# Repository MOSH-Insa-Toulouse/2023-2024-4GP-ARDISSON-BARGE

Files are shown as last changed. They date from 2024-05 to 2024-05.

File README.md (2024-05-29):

# 4GP 2023/2024 - Projet de capteur _low-tech_ en graphite - Par Cyril ARDISSON et Kévin BARGE <br>

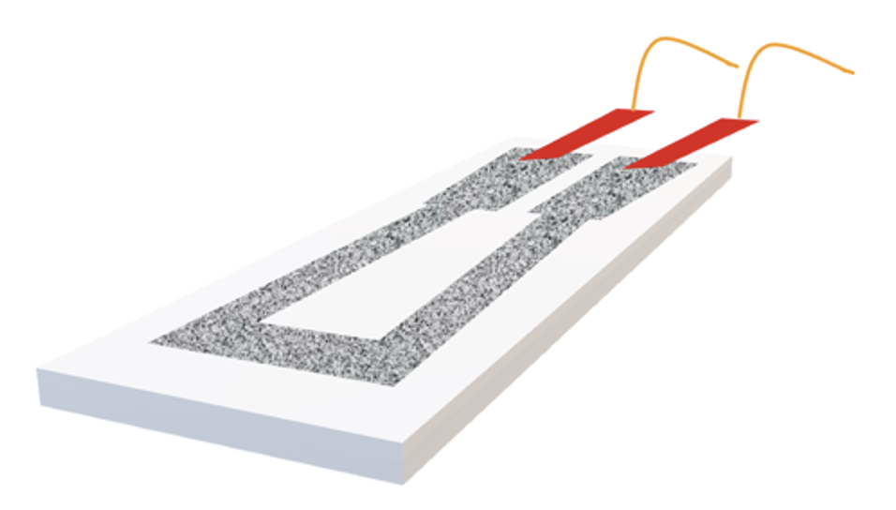
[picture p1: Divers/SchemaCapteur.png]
Visuel capteur


## Table des matières
✓ [Contacts](#contacts) <br>
✓ [Contexte](#contexte) <br>
✓ [Livrables](#livrables) <br>
✓ [Matériel requis](#matériel-requis) <br>
[1- Simulation sous LTSpice](#1--simulation-sous-ltspice) <br>
[2- Design du PCB sous KiCAD](#2--design-du-pcb-sous-kicad) <br>
[3- Code sous Arduino IDE](#3--code-sous-arduino-ide) <br>
[4- Application Android](#4--application-android) <br>
[5- Réalisation du shield](#5--réalisation-du-shield) <br>
[6- Banc de test et principaux résultats](#6--banc-de-test-et-principaux-résultats) <br>
[7- Datasheet du capteur](#7--datasheet-du-capteur) <br>
✓ [Conclusions et analyse critique du projet](#conclusions-et-analyse-critique-du-projet) <br>
___
## Contacts
Cyril ARDISSON : [ardisson@insa-toulouse.fr](mailto:ardisson@insa-toulouse.fr) <br>
Kévin BARGE : [barge@insa-toulouse.fr](mailto:barge@insa-toulouse.fr) <br>
___
## Contexte
Dans le cadre de l'UF de 4ème Année spécialité Génie Physique "Du capteur au banc de test" (I4GPMH21), nous avons réalisé l'évaluation d'une technologie low-tech : un capteur en graphite, composé de papier, recouvert d'une couche de graphite qu'on peut simplement trouver dans les crayons à papier ! En se déformant, le nombre de particules de graphite reliées varie, ce qui entraîne une modification de sa résistance. De cela, on peut donc induire la déformation. Sur le même principe qu'une jauge de contrainte (ici low-tech !). Ce travail se base sur les travaux de chercheurs de l'Université de Northwestern (Etats-Unis), publiés en 2014 dans l'article "_Pencil Drawn Strain Gauges and Chemiresistors on Paper_" (Cheng-Wei Lin, Zhibo Zhao, Jaemyung Kim & Jiaxing Huang). 

Afin de réaliser ce projet, plusieurs étapes ont été réalisées : simulation électronique, design de PCB et fabrication, programmation d'un Arduino Uno et d'une IHM, mise en place d'un banc de test et écriture d'une datasheet.

Ici, nous faisons le tour de tout ce qui a été fait dans le cadre de ce projet.

___
## Livrables
Plusieurs livrables sont attendus :

✓ **Le shield PCB connecté à une carte Arduino Uno**, composé : du capteur en graphite, d'un montage amplificateur transimpédance et d'un module Bluetooth. D'autres composants peuvent aussi être implémentés (*) : écran OLED, encodeur rotatoire, potentiomètre digital, flex sensor et connexions pour un servo-moteur ; <br>
✓ **Le code Arduino** permettant d'effectuer les mesures du capteur et de contrôler les composants implémentés ; <br>
✓ **L'APK Android** permettant d'interfacer le shield et le code Arduino correspondant : l'IHM en résumé ; <br>
✓ **Le / Les code(s) Arduino** permettant d'effectuer les tests du capteur ; <br>
✓ **La datasheet du capteur** reprenant toutes ses caractéristiques ainsi que ses tests. <br>

(*) Pour notre projet, nous avons décidés d'implémenter sur notre shield : l'écran OLED, l'encodeur rotatoire, le potentiomètre digital et le flex sensor. 
___
## Matériel requis
Afin de réaliser notre dispositif, nous avons eu besoin de :

Pour le montage amplificateur transimpédance : <br>
✓ Résistances : une de $1\ \text{k}\Omega$, une de $10\ \text{k}\Omega$ et deux de $100\ \text{k}\Omega$ - une troisième de $100\ \text{k}\Omega$ peut être prévue, mais peut aussi être substituée par une résistance variable (le potentiomètre digital), choix que l'on a fait ; <br>
✓ Un potentiomètre digital (si substitution d'une résistance de $100\ \text{k}\Omega$) : ici, choix du MCP41050 ; <br>
✓ Capacités : trois de $100\ \text{nF}$ et une de $1\ \mu\text{F}$ ; <br>
✓ Un amplificateur opérationnel : ici, choix du LTC1050 ; <br>

Pour le reste du dispositif : <br>
✓ Un module Bluetooth : ici, choix du HC05 ; <br>
✓ Un écran OLED de dimension 128*64 ; <br>
✓ Un encodeur rotatoire ; <br>
✓ Un flex sensor.
___
## 1- Simulation sous LTSpice
Notre capteur en graphite a une résistance de l'ordre du ${G}\Omega$, ce qui conduit, en appliquant une tension d'entrée de $5\ \text{V}$, à obtenir un courant de quelques ${nA}$. En conséquence, notre Arduino Uno ne pourra pas le lire. Il y a donc nécessité d'amplifier ce signal : c'est donc ce pourquoi nous mettons en place un **montage amplificateur transimpédance**. <br>

**_Description du montage amplificateur transimpédance_** <br>
Notre montage est composé de 4 zones importantes, une pour l'amplification et trois qui correspondent à des filtres : <br>
✓ Un premier filtre en entrée de l'amplificateur (${R1}$ et ${C1}$) : il correspond à un filtre passe-bas, qui permet de filtrer le bruit en courant sur le signal d'entrée ; <br>
✓ Un second filtre couplé à l'amplificateur (${R3}$ et ${C4}$) : il correspond aussi à un filtre passe-bas, qui permet de filtrer la composante 50 Hz du réseau électrique ; <br>
✓ et un troisième filtre en sorti de l'amplificateur (${R6}$ et ${C2}$) : pour filtrer le bruit lié au traitement opéré par l'amplificateur. <br>

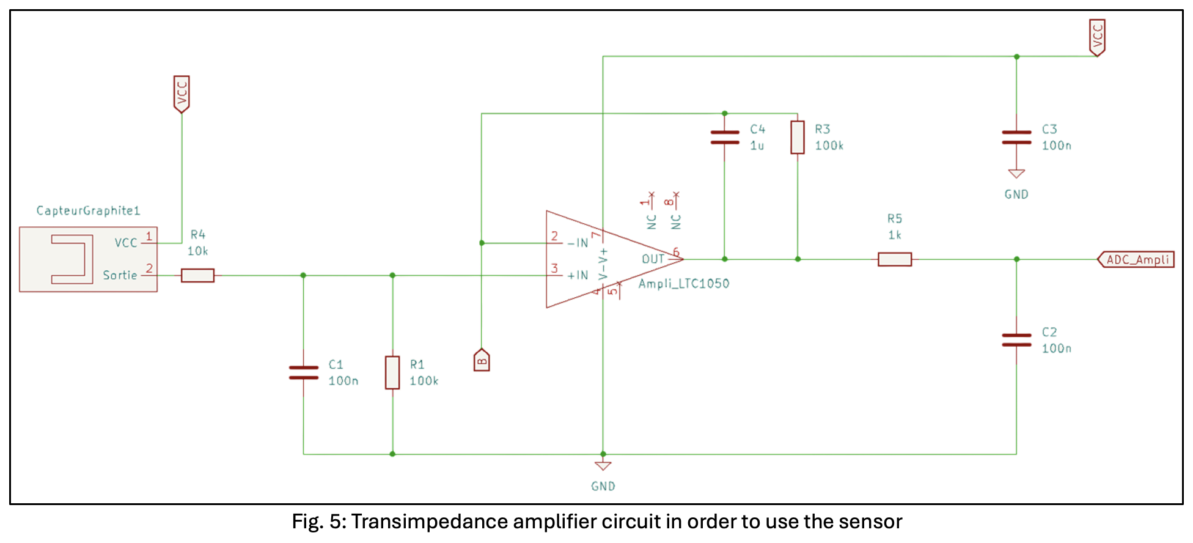
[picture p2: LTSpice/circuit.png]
Montage amplificateur transimpédance
<br>

Sur LTSpice, nous avons testé ce montage en deux temps. <br>

**_Simulations réalisées avec LTSpice_** <br>
Sur LTSpice, nous avons testé ce montage en deux temps. <br>

D'abord, nous avons effectué une première simulation pour vérifier si l'amplification était bien effective. Comme on peut le constater ci-dessous, le signal est bien amplifié à $1\ \text{V}$ : l'Arduino pourra donc l'interpréter. <br>

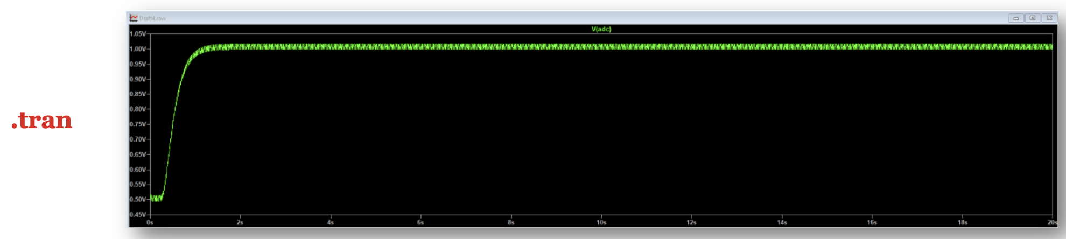
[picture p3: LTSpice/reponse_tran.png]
Réponse à .tran
<br>

Enfin, nous avons effectué une seconde simulation, afin d'observer la réponse à un courant alternatif et ainsi de vérifier que le signal est bien filtré. Comme on peut aussi le constater ci-dessous, le signal paraît filtré, successivement par les 3 filtres. <br>

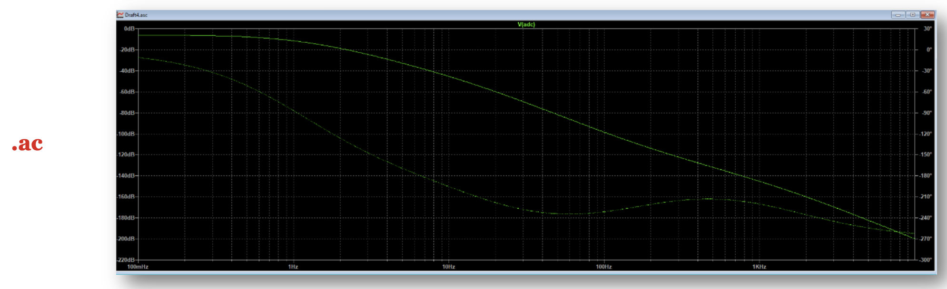
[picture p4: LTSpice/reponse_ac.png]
Réponse à .ac
<br><br>
___
## 2- Design du PCB sous KiCAD
Ici, nous sommes repartis du montage décrit ci-dessus, avec quelques modifications et ajouts de composants. Nous avons utilisé le logiciel KiCad 7.0 : <br>
✓ Comme mentionné auparavant, nous avons remplacé ${R2}$ par le potentiomètre digital ; <br>
✓ Ajout d'un module Bluetooth afin d'assurer la communication entre le PCB et l'APK Android ; <br>
✓ Ajout d'un écran OLED afin d'afficher 3 menus différents ; <br>
✓ Ajout d'un encodeur rotatoire afin de passer de menu en menu ; <br>
✓ Et enfin, ajout d'un flex sensor, en vu des tests finaux. <br>

Pour se faire, nous avons débuté par la création de notre propre bibliothèque de symboles correspondant à nos composants. Puis, nous avons procédé à la création de la schématique électrique de l'ensemble du montage. L'image ci-dessous correspond à cette schématique. <br>

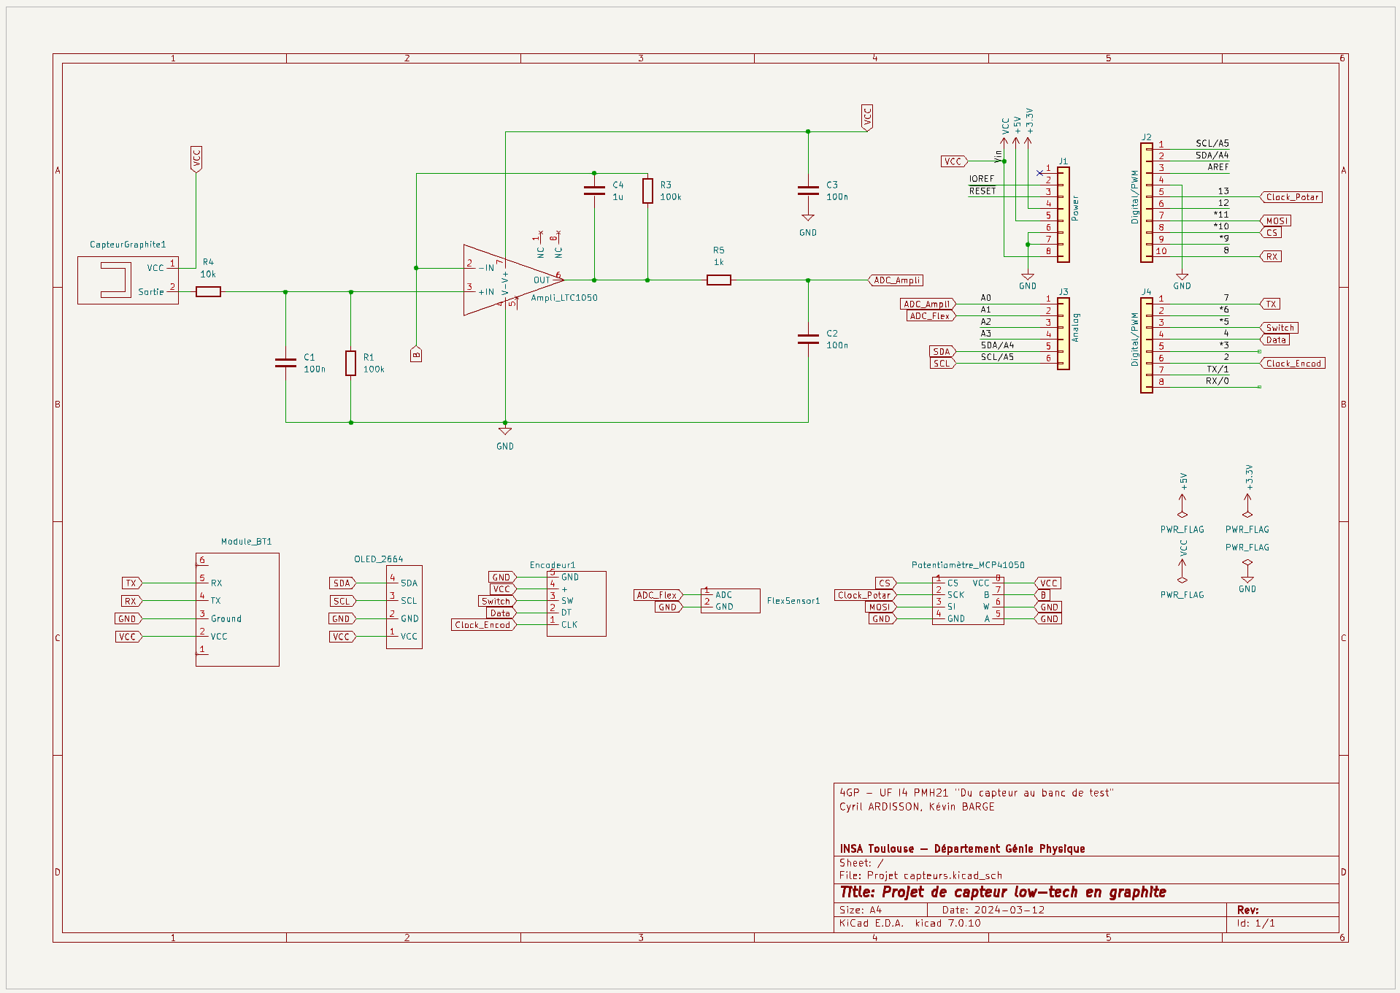
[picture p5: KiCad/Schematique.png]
Schématique KiCad
 <br>

Puis, nous avons créé les empreintes de nos composants, en respectant certaines dimensions, en vu de l'impression du PCB (diamètre des trous, forme des empreintes, etc.). Nous sommes ensuite passés à la disposition des composants sur le PCB : une étape fastidieuse avec des compromis afin d'obtenir le placement le plus efficace (en considérant les connexions entre composants, en évitant d'avoir recours aux vias, etc.)... L'image ci-dessous correspond au résultat final de notre PCB, et sa vue en 3D correspondante :

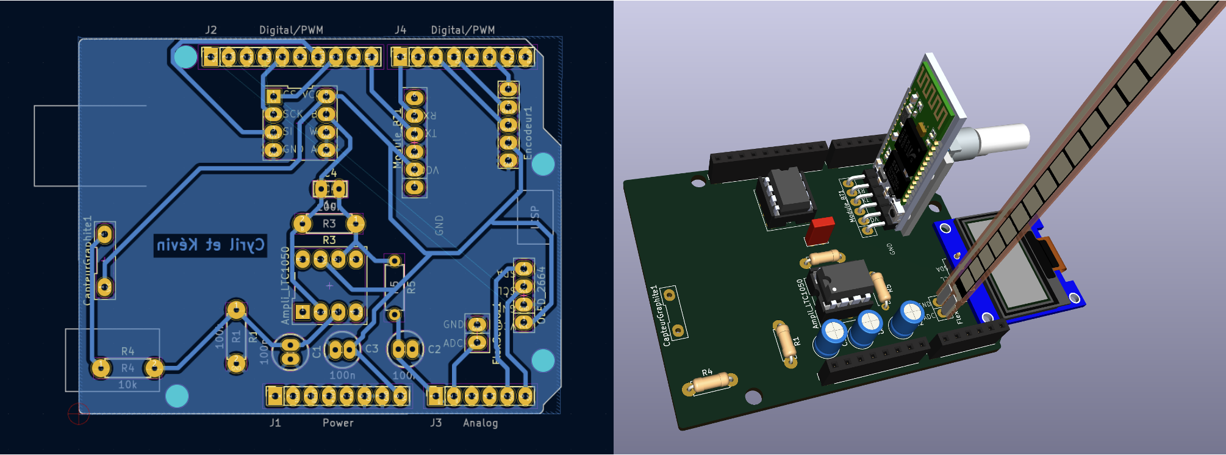
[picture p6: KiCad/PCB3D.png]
PCB et vue 3B
 <br>

Les fichiers KiCad sont disponibles dans le dossier [KiCad](https://github.com/MOSH-Insa-Toulouse/2023-2024-4GP-ARDISSON-BARGE/tree/main/KiCad). 
___
## 3- Code sous Arduino IDE
Le code de contrôle, qui permet d'effectuer les mesures du capteur et de contrôler les composants implémentés, a été développé sous Arduino IDE 2.3.2. <br>

Pour communiquer en Bluetooth, nous avons utilisé la bibliothèque _SoftwareSerial.h_ et pour contrôler l'écran OLED, la bibliothèque _Adafruit_SSD1306.h_. <br>

Notamment, en plus de la communication Bluetooth entre notre PCB et l'application Bluetooth, notre code permet de contrôler deux menus à afficher sur l'écran OLED : <br>
✓ Un menu pour afficher la résistance du capteur _en direct_ ; <br>
✓ Et un menu pour afficher la résistance du flex sensor _en direct_. <br>

Les mesures se font toutes les 100 ms. <br>

Le code complet est disponible [ici](https://github.com/MOSH-Insa-Toulouse/2023-2024-4GP-ARDISSON-BARGE/blob/main/ArduinoIDE/ARDISSON-BARGE_CodeFinal.ino). <br>
___
## 4- Application Android
Nous avons créé une application en guise d'interface, avec MIT App Inventor. <br>

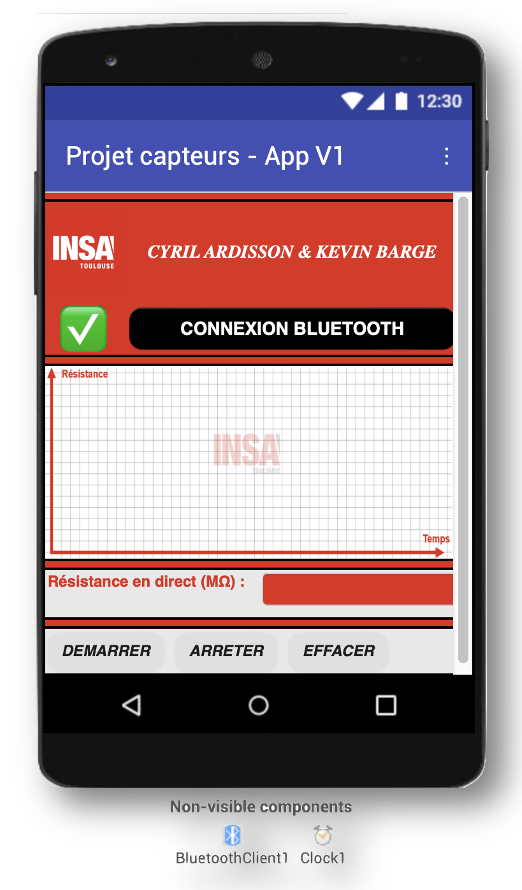
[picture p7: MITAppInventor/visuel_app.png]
Visuel de l'application
 <br>

Cette application se veut simple et permet : <br>
✓ De se connecter au module Bluetooth du PCB afin de communiquer avec ce dernier ; <br>
✓ D'afficher sur un graphe la résistance du capteur en fonction du temps (où on peut démarrer / arrêter l'acquisition + effacer le graphe) ; <br>
✓ Et d'afficher la résistance "en direct". <br>

_Néanmoins, on rencontre tout de même quelques problèmes de connexion entre l'app qu'on installe sur un smartphone Android et le module Bluetooth. Bien souvent, aucune donnée n'est récupérée._ <br>

L'application est disponible [ici](https://github.com/MOSH-Insa-Toulouse/2023-2024-4GP-ARDISSON-BARGE/blob/main/MITAppInventor). <br>
___
## 5- Réalisation du shield
Fin mars, nous avons pu passer à la réalisation _physique_ de notre PCB. Voici les étapes de fabrication réalisées, avec l'aide de Cathy Crouzet (_merci !_) : <br>

Étape 0 (_importante !_) : vérification du PCB sous KiCad, notamment test DRC <br>
Étape 1 : édition du masque de gravure sous KiCad <br>
Étape 2 : insolation UV d'une plaquette d'époxy (recouverte d'une couche de cuivre et de résine photosensible) <br>
Étape 3 : immersion de la plaquette dans un révélateur afin d'éliminer la résine non-insolée <br>
Étape 4 : immersion de la plaquette dans du perchlorure de fer pour graver les pistes <br>
Étape 5 : nettoyage de la plaquette avec de l'acétone pour retirer la résine restante <br>
Étape 6 : perçage des trous et placement des composants sur le PCB <br>

L'image ci-dessous illustre le rendu final de notre PCB : <br>

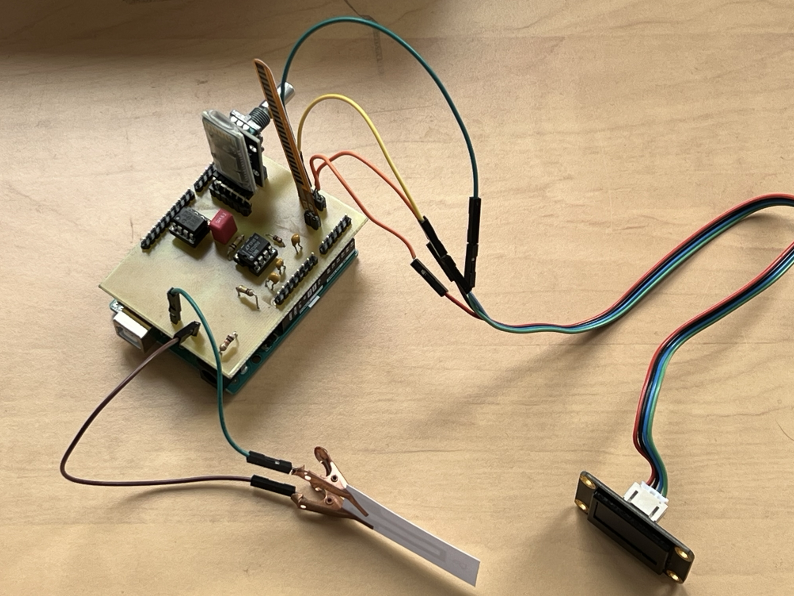
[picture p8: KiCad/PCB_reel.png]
PCB en vrai
 <br>
___
## 6- Banc de test et principaux résultats
Afin de tester nos capteurs, nous avons utilisés le banc de test suivant, composé de 7 demi-cercles, avec des diamètres de 2 à 5 cm (0,5 cm d'écart entre chaque). <br>

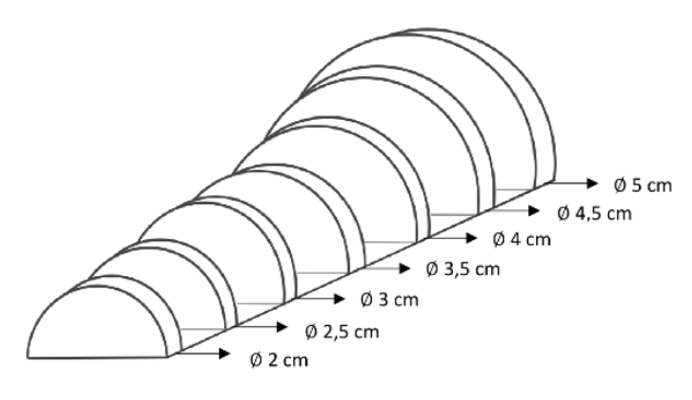
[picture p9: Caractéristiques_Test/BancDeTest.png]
Visuel banc de test
 <br>

Ce banc de test nous permet d'obtenir la variation de résistance $\frac{\Delta R}{R_0}$ en fonction de la déformation $\epsilon = \frac{e}{D}$ avec $e$ l'épaisseur du capteur (ici 0,2 mm) et $D$ le diamètre du cercle considéré. <br>

Nous avons réalisé les tests en *compression* et en *tension*. <br>

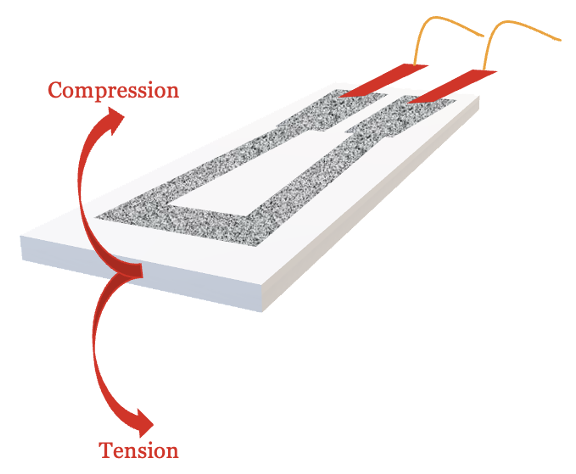
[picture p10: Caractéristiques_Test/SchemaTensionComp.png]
Visuel capteur en compression et tension
 <br>

Nous avons effectués les tests avec des capteurs recouverts de deux types de graphite différents : d'un crayon HB et d'un crayon 2B. (*) <br>

Voici les caractéristiques en compression : <br>
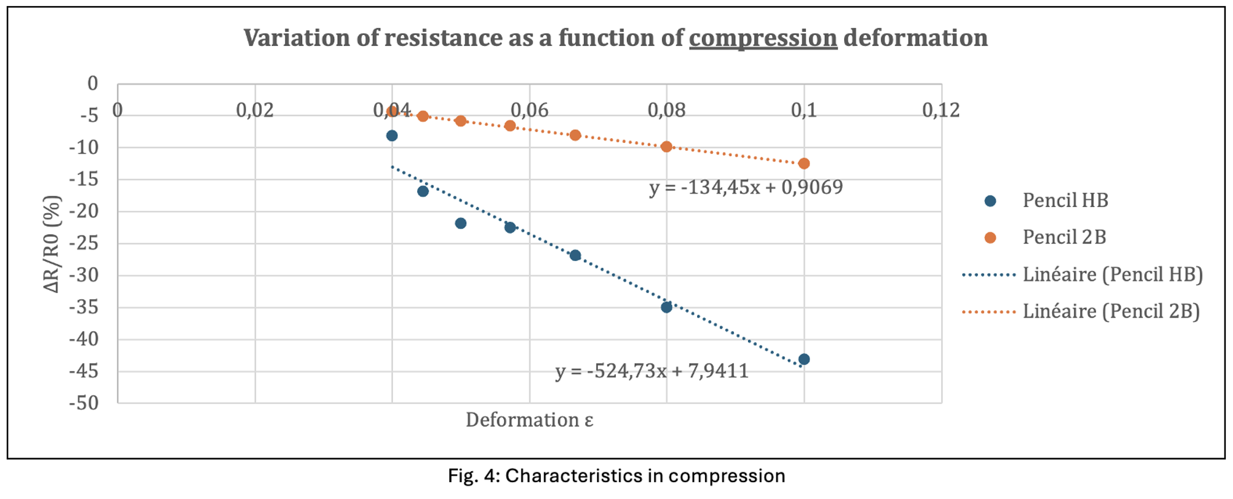
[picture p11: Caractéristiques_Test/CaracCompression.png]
Caractéristique en compression
 <br>

Et les caractéristiques en tension : <br>
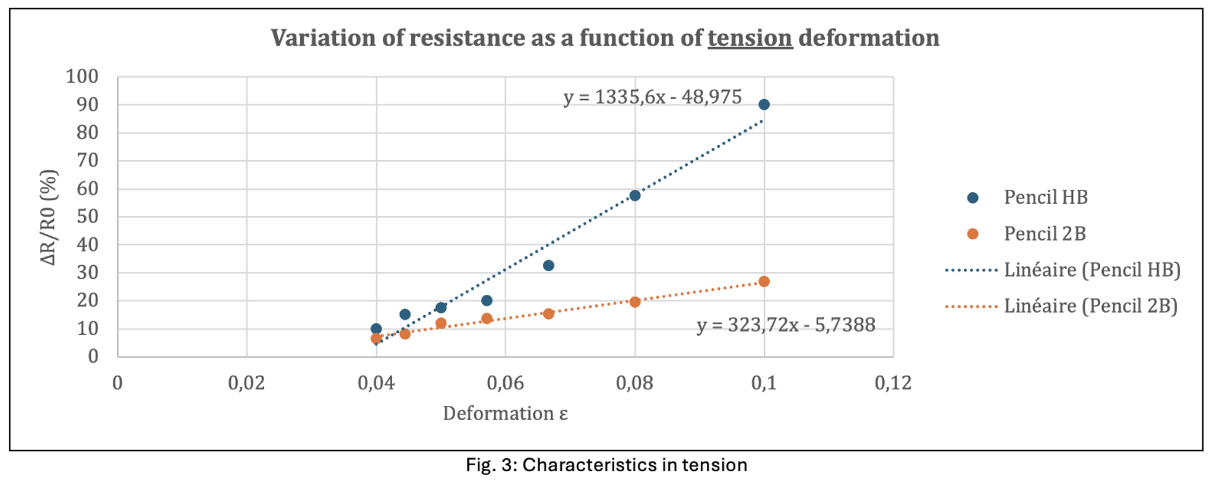
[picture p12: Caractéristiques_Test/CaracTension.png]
Caractéristique en tension
 <br>

On peut donc remarquer que la résistance diminue lorsqu'on augmente la compression, alors que la résistance augmente lorsqu'on augmente la tension. Ceci semble cohérent : en compression, la distance entre les atomes diminue et donc la résistance dimunue en conséquence. L'inverse est vrai en tension. <br>

De plus, on voit qu'avec un crayon plus gras (2B étant plus gras que HB - plus de carbone !), la variation relative de résistance est moins importante. 

Enfin, pour comparer, nous avons aussi réalisé le test en tension (car cela ne fonctionne pas en compression !) avec le flex sensor : <br>
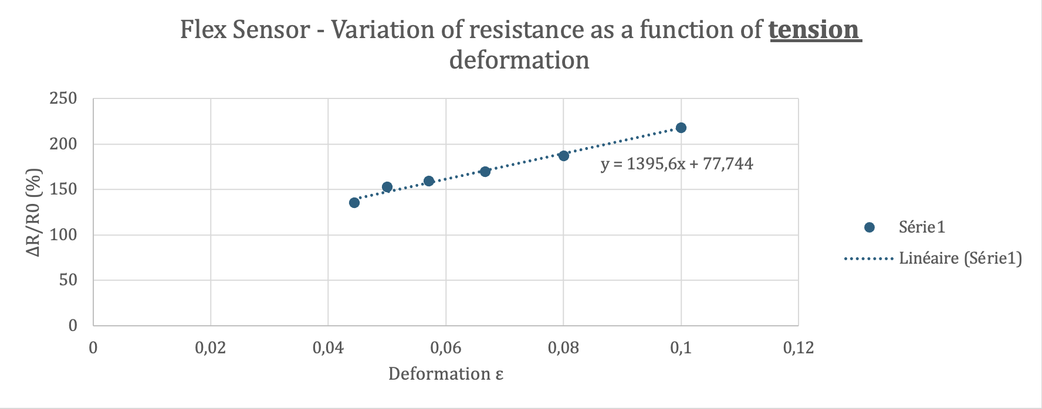
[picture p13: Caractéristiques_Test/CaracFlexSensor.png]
Caractéristique flex sensor
 <br>

On remarque donc que, en comparaison de nos capteurs, le flex sensor semble plus sensible, ce qui semble faire sens. Pour des déformations importantes, il semble aussi être plus apte à les tolérer, "plus solide". <br>

(*) _Nous voulions aussi tester notre capteur en graphite issu d'un crayon B, mais les tests n'étaient pas concluants. En effet, cette méthode de test donne des résultats assez aléatoirement. L'usage d'un servomoteur avec une inclinaison pas à pas sur les demi-cercles pourrait peut-être donner des résultats plus stables. Dans la même optique, une méthode de contrôle de la quantité de graphique déposée sur les capteurs serait la bienvenue, étant assez aléatoire. Tout cela conduit donc à avoir, en l'état, des conditions de test assez peu reconductibles._ <br>
___
## 7- Datasheet du capteur
La datasheet de notre capteur est disponible [ici](https://github.com/MOSH-Insa-Toulouse/2023-2024-4GP-ARDISSON-BARGE/blob/main/Datasheet/ARDISSON-BARGE_Datasheet.pdf).  <br>
___
## Conclusions et analyse critique du projet
Ce projet a été très enrichissant, nous donnant une réelle perspective du travail de l'ingénieur, en le conduisant de bout en bout, des simulations à la datasheet. On a pu avoir avoir une bonne perspective d'une variété de compétences (simulation électronique, développement informatique, design d'un montage électronique, fabrication _physique_ de ce dernier, etc.). En ce sens, c'est donc assez professionnalisant, et gratifiant d'avoir un produit final. <br>

En ce qui concerne le capteur produit, il est fonctionnel et les tests nous permettent de dégager des tendances cohérentes avec la physique. Néanmoins, comme souligné plus haut, les conditions de tests sont rudimentaires et peu reproductibles, ce qui conduit à tout de même obtenir des résultats assez aléatoires. Il faut donc prendre du recul. <br>

Maintenant, il est clair que dans un objectif pédagogique, ce projet est idéal ! <br>

_En espérant que notre société GazouTech va prospérer grâce à ce dernier !_ <br>

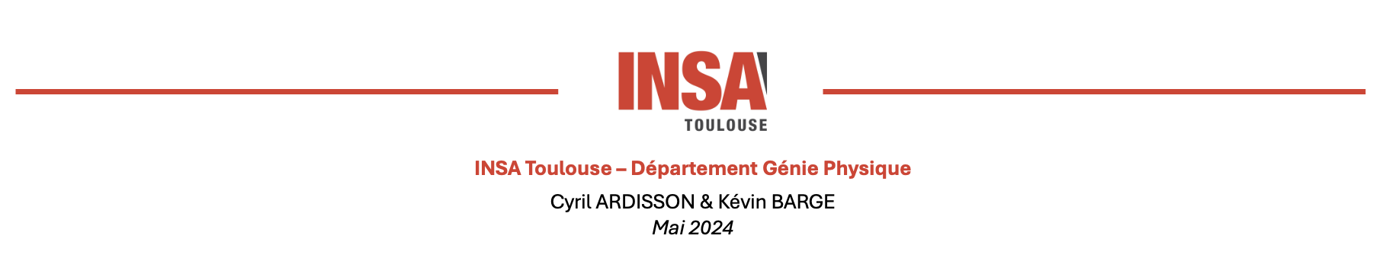
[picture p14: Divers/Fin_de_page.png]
Fin de page
<br>

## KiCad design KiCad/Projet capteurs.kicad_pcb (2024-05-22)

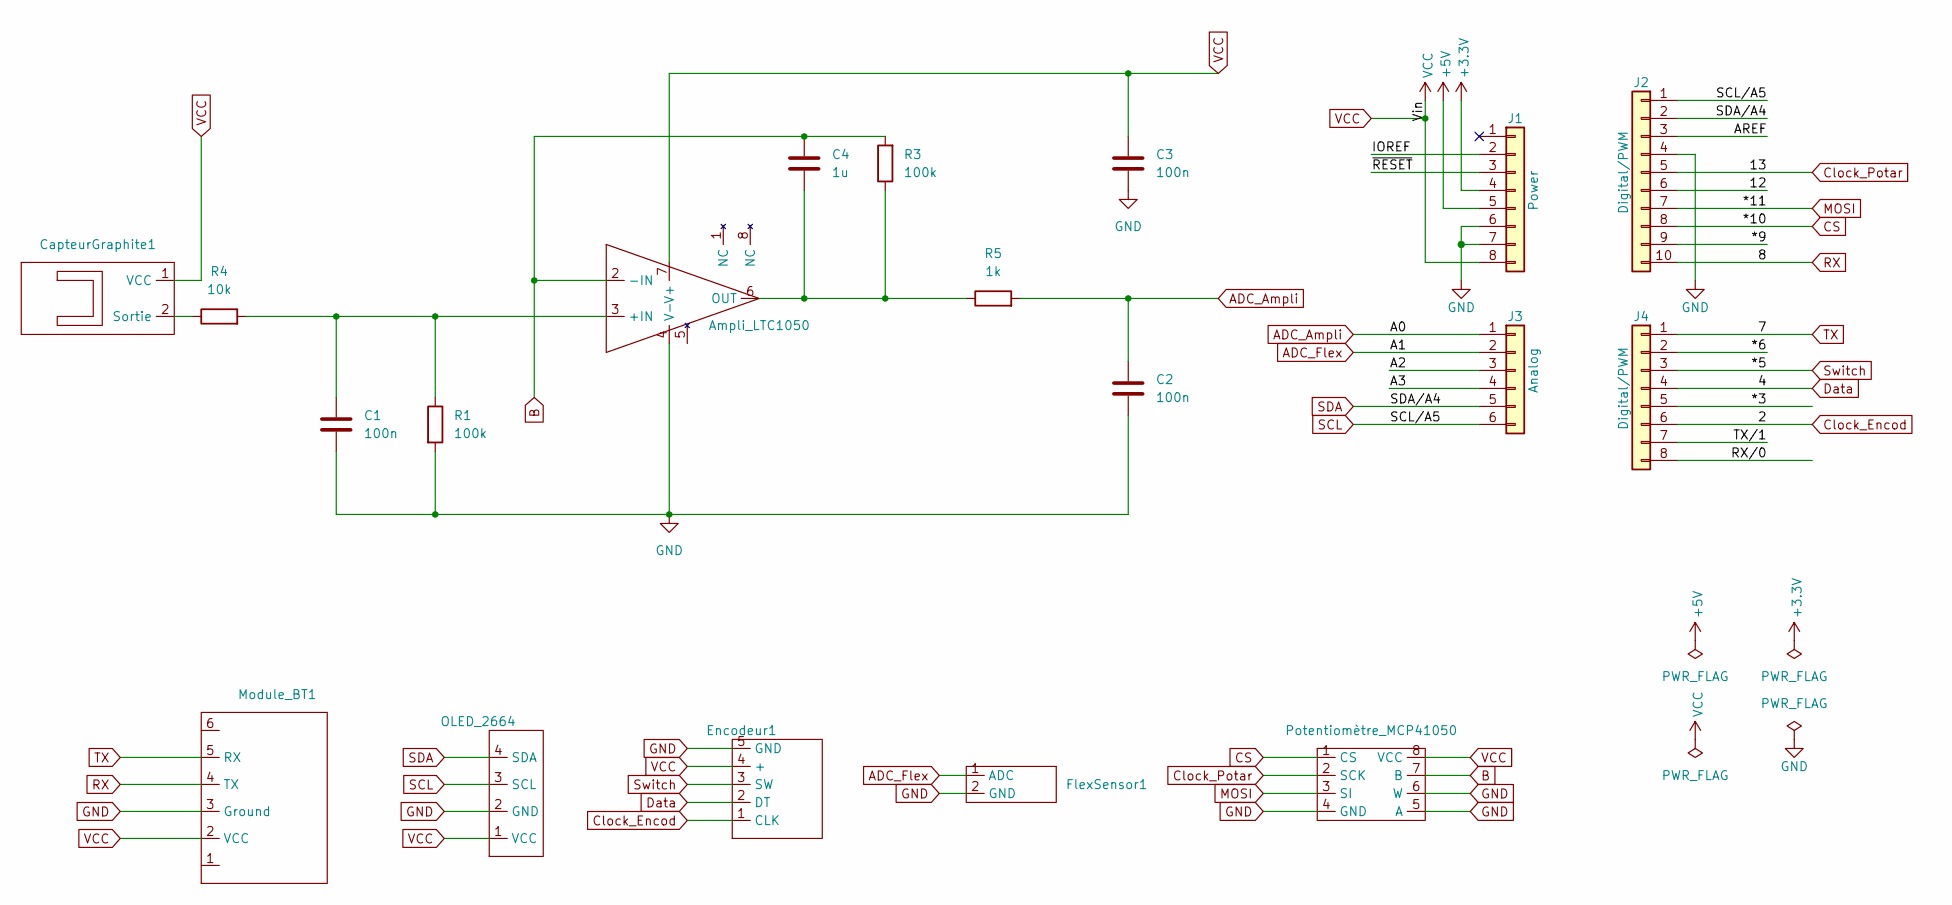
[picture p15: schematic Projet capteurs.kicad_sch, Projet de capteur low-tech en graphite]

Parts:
Ampli_LTC1050: Ampli_LTC1050
C1, C2, C3: 100n; C_Radial_D5.0mm_H7.0mm_P2.00mm
C4: 1u; C_Rect_L4.6mm_W2.0mm_P2.50mm_MKS02_FKP02
CapteurGraphite1: CapteurGraphite
Encodeur1: Encodeur
FlexSensor1: FlexSensor
J1: Power; PinSocket_1x08_P2.54mm_Vertical
J2: Digital/PWM; PinSocket_1x10_P2.54mm_Vertical
J3: Analog; PinSocket_1x06_P2.54mm_Vertical
J4: Digital/PWM; PinSocket_1x08_P2.54mm_Vertical
Module_BT1: Module_BT_new
OLED_2664: OLED_2864
Potentiomètre_MCP41050: MCP41050
R1, R3: 100k; R_Axial_DIN0207_L6.3mm_D2.5mm_P7.62mm_Horizontal
R4: 10k; R_Axial_DIN0207_L6.3mm_D2.5mm_P7.62mm_Horizontal
R5: 1k; R_Axial_DIN0207_L6.3mm_D2.5mm_P7.62mm_Horizontal

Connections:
+3V3: J1.4
+5V: J1.5
/12: J2.6
/*3: J4.5
/*6: J4.2
/*9: J2.9
/A2: J3.3
/A3: J3.4
/AREF: J2.3
/IOREF: J1.2
/RX/0: J4.8
/TX/1: J4.7
/~RESET: J1.3
ADC_Ampli: C2.1, J3.1, R5.2
ADC_Flex: FlexSensor1.1 (ADC), J3.2
B: Ampli_LTC1050.2 (-IN), C4.1, Potentiomètre_MCP41050.7 (B), R3.2
CS: J2.8, Potentiomètre_MCP41050.1 (CS)
Clock_Encod: Encodeur1.1 (CLK), J4.6
Clock_Potar: J2.5, Potentiomètre_MCP41050.2 (SCK)
Data: Encodeur1.2 (DT), J4.4
GND: Ampli_LTC1050.4 (V-), C1.2, C2.2, C3.2, Encodeur1.5 (GND), FlexSensor1.2 (GND), J1.6, J1.7, J2.4, Module_BT1.3 (Ground), OLED_2664.2 (GND), Potentiomètre_MCP41050.4 (GND), Potentiomètre_MCP41050.5 (A), Potentiomètre_MCP41050.6 (W), R1.2
MOSI: J2.7, Potentiomètre_MCP41050.3 (SI)
unnamed: Ampli_LTC1050.3 (+IN), C1.1, R1.1, R4.2
unnamed: Ampli_LTC1050.6 (OUT), C4.2, R3.1, R5.1
unnamed: CapteurGraphite1.2 (Sortie), R4.1
RX: J2.10, Module_BT1.4 (TX)
SCL: J2.1, J3.6, OLED_2664.3 (SCL)
SDA: J2.2, J3.5, OLED_2664.4 (SDA)
Switch: Encodeur1.3 (SW), J4.3
TX: J4.1, Module_BT1.5 (RX)
VCC: Ampli_LTC1050.7 (V+), C3.1, CapteurGraphite1.1 (VCC), Encodeur1.4 (+), J1.8, Module_BT1.2 (VCC), OLED_2664.1 (VCC), Potentiomètre_MCP41050.8 (VCC)

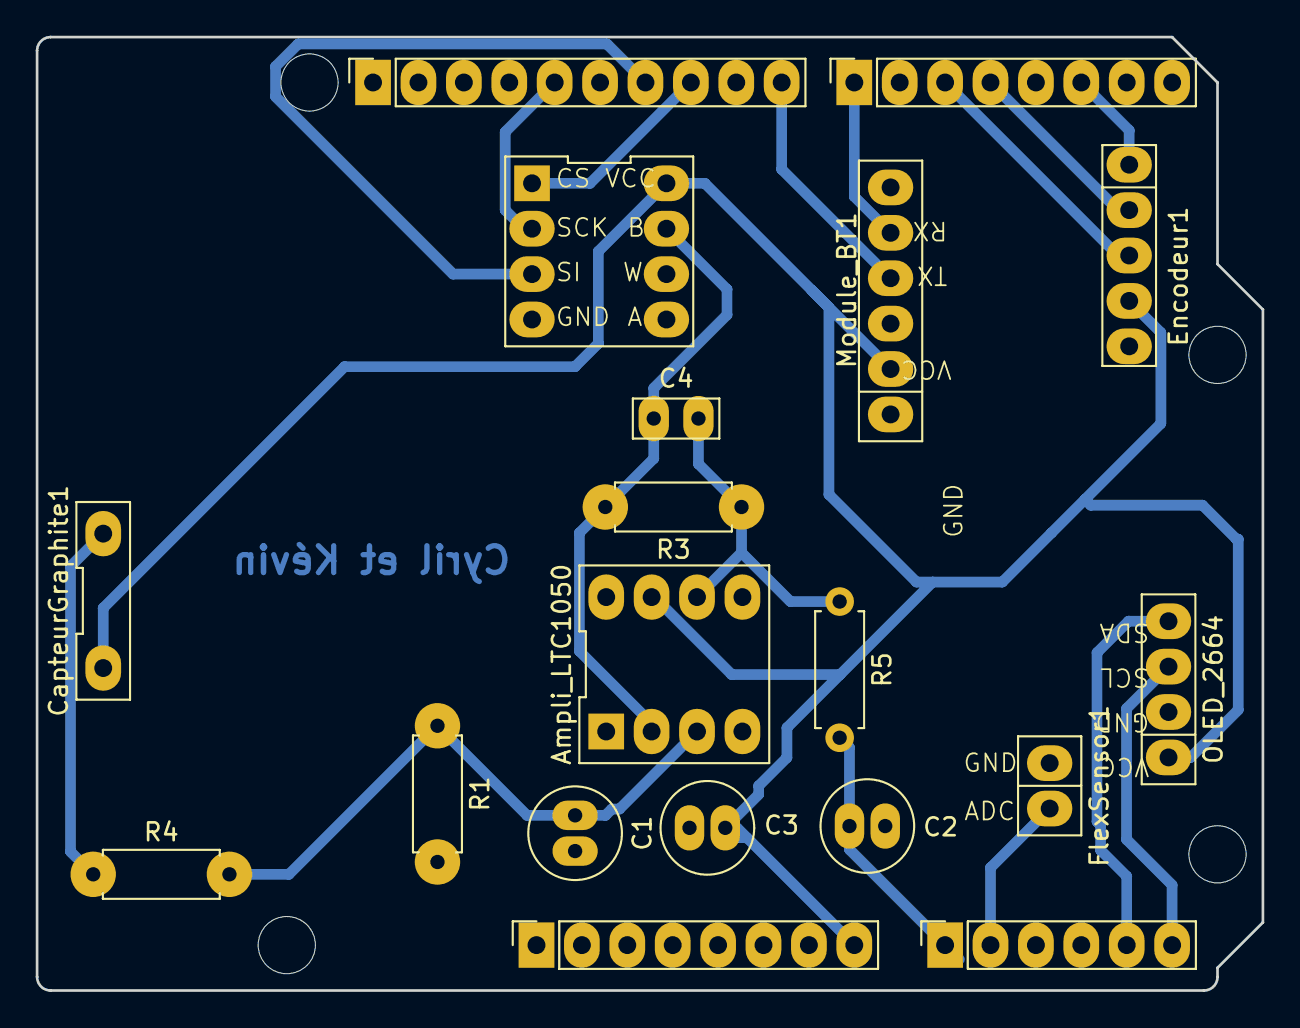
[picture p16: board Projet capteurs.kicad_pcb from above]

Board: 2 copper layers, 68.6 x 53.3 mm, 23 parts (0 on the bottom side), 18 nets.

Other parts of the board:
MH1, MH2, MH3, MH4: MountingHole_3.2mm

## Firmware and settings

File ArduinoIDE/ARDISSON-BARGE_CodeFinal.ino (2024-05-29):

#include <Adafruit_SSD1306.h>
#include <SoftwareSerial.h>
#include <SPI.h>

#define nombreDePixelsEnLargeur 128         // Taille de l'écran OLED, en pixel, au niveau de sa largeur
#define nombreDePixelsEnHauteur 64          // Taille de l'écran OLED, en pixel, au niveau de sa hauteur
#define brocheResetOLED         -1          // Reset de l'OLED partagé avec l'Arduino (d'où la valeur à -1, et non un numéro de pin)
#define adresseI2CecranOLED     0x3C        // Adresse de "mon" écran OLED sur le bus i2c (généralement égal à 0x3C ou 0x3D)

//partie pour le digitalpot
// Define the MCP41100 OP command bits (only one POT)
// Note: command byte format xxCCxxPP, CC command, PP pot number (01 if selected) 
#define MCP_NOP 0b00000000
#define MCP_WRITE 0b00010001
#define MCP_SHTDWN 0b00100001
const int ssMCPin = 10; // Define the slave select for the digital pot
#define WAIT_DELAY 5000


//partie pour le module BT
#define rxPin 8 //Broche 8 en tant que RX, � raccorder sur TX du HC-05
#define txPin 7 //Broche 7 en tant que RX, � raccorder sur RX du HC-05
SoftwareSerial mySerial(rxPin ,txPin); //D�finition du software serial

//partie pour l'encodeurrot
#define encoder0PinA  2  //CLK Output A Do not use other pin for clock as we are using interrupt
#define encoder0PinB  4  //DT Output B
#define Switch 5 // Switch connection if available
const unsigned long limite = 50 ;
volatile unsigned int encoder0Pos = 34;
volatile unsigned int choixmenu = 0;

Adafruit_SSD1306 ecranOLED(nombreDePixelsEnLargeur, nombreDePixelsEnHauteur, &Wire, brocheResetOLED);


const int flexPin = A1;      // Pin connected to voltage divider output
// Change these constants according to your project's design
// const float VCC = 5;      // voltage at Ardunio 5V line
const float R_DIV = 38000.0;  // resistor used to create a voltage divider
const float flatResistance = 31000.0; // resistance when flat
const float bendResistance = 100000.0;  // resistance at 90 deg

// Résistances pour calcul de la résistance du capteur
float R1 = 100000.0;
float R2 = 1000.0;
float R3 = 100000.0;
float R5 = 10000.0;
float R6 = 100000.0;
float Vcc = 5.0;
float Vs = 0.0;
float calibre = 0.000001; //calibre en MOhm

int Encodeur ; 
int temps = 0 ;

void SPIWrite(uint8_t cmd, uint8_t data, uint8_t ssPin) // SPI write the command and data to the MCP IC connected to the ssPin
{
  SPI.beginTransaction(SPISettings(14000000, MSBFIRST, SPI_MODE0)); //https://www.arduino.cc/en/Reference/SPISettings
  
  digitalWrite(ssPin, LOW); // SS pin low to select chip
  
  SPI.transfer(cmd);        // Send command code
  SPI.transfer(data);       // Send associated value
  
  digitalWrite(ssPin, HIGH);// SS pin high to de-select chip
  SPI.endTransaction();
}

void setup() {

  // pour le module BT dans le setup
  pinMode(rxPin,INPUT);
  pinMode(txPin,OUTPUT);

  //partie pour le digitalpot dans le setup
  pinMode (ssMCPin, OUTPUT); //select pin output
  digitalWrite(ssMCPin, HIGH); //SPI chip disabled
  SPI.begin(); 

  // initialize serial communication at 9600 bits per second:
  mySerial.begin(9600) ;
  Serial.begin(9600) ;

  //pour l'encodeurrot
  pinMode(encoder0PinA, INPUT); 
  digitalWrite(encoder0PinA, HIGH);       // turn on pullup resistor
  pinMode(encoder0PinB, INPUT); 
  digitalWrite(encoder0PinB, HIGH);       // turn on pullup resistor
  attachInterrupt(0, doEncoder, RISING); // encoder pin on interrupt 0 - pin2
 
  // Initialisation de l'écran OLED
  if(!ecranOLED.begin(SSD1306_SWITCHCAPVCC, adresseI2CecranOLED)){
    while(1);                               // Arrêt du programme (boucle infinie) si échec d'initialisation

  }

    pinMode(flexPin, INPUT);
}

void loop() {


  Vs = analogRead(A0)*5.0/1024.0 ;
  float ValResistance = ((R1*((R2+R3)/R2)*(Vcc/Vs))-R5-R1)*calibre ;
  mySerial.write(analogRead(A0)) ;
  Serial.println(analogRead(A0)) ;

  // Read the ADC, and calculate voltage and resistance from it
  int ADCflex = analogRead(flexPin);
  float Vflex = ADCflex * Vcc / 1023.0;
  float Rflex = R_DIV * (Vcc / Vflex - 1.0);
  // Use the calculated resistance to estimate the sensor's bend angle:
  float angle = map(Rflex, flatResistance, bendResistance, 0, 90.0);

  Encodeur = 3*encoder0Pos ;

if (Encodeur < 0) {
  encoder0Pos = 24 ;
}

else if (Encodeur > 250) {
  encoder0Pos = 67 ;
}

// Menu résistance capteur graphite
if (Encodeur <= 75) {
  ecranOLED.clearDisplay();
  ecranOLED.setTextColor(SSD1306_WHITE);
  ecranOLED.setTextSize(3);
  ecranOLED.setCursor(0, 0);

  ecranOLED.setTextSize(1);
  ecranOLED.println("val capteur graphite");
  ecranOLED.print(ValResistance);
  ecranOLED.println(" Ohm");
}

// Menu flex sensor
else if (Encodeur >= 75 && Encodeur <= 110) {
  ecranOLED.clearDisplay();
  ecranOLED.setTextColor(SSD1306_WHITE);
  ecranOLED.setTextSize(3);
  ecranOLED.setCursor(0, 0);

  ecranOLED.setTextSize(1);
  ecranOLED.println("valeur capteur flex");
  ecranOLED.println("Res_flex:" + String(Rflex) + " MOhm");
  ecranOLED.println("Bend_flex: " + String(angle) + " deg");
}

}

ecranOLED.display(); // Transfert le buffer à l'écran

delay(100);  // delay in between reads for stability

}

// Pour améliorer la fiabilité de l'encodeur rotatoire
void doEncoder() {
  if ( (millis() - temps) > limite) {

    if (digitalRead(encoder0PinB)==HIGH) {
      encoder0Pos++;
    } 
    
    else {
      encoder0Pos--;
    }
    
    temps = millis();
  
  } 

  }
